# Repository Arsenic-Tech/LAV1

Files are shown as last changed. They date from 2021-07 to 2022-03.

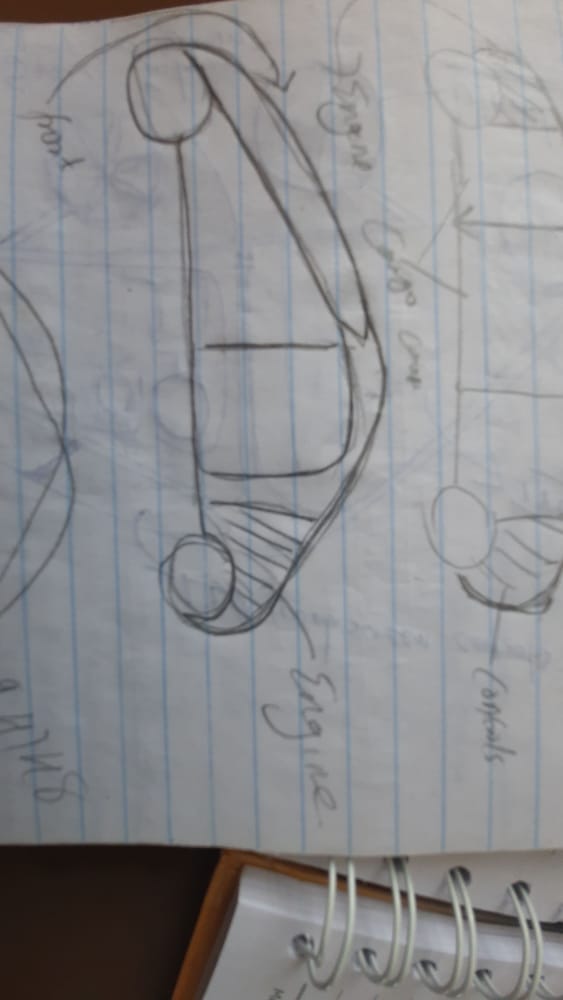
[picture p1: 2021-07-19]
IMGS/drone design2.jpg

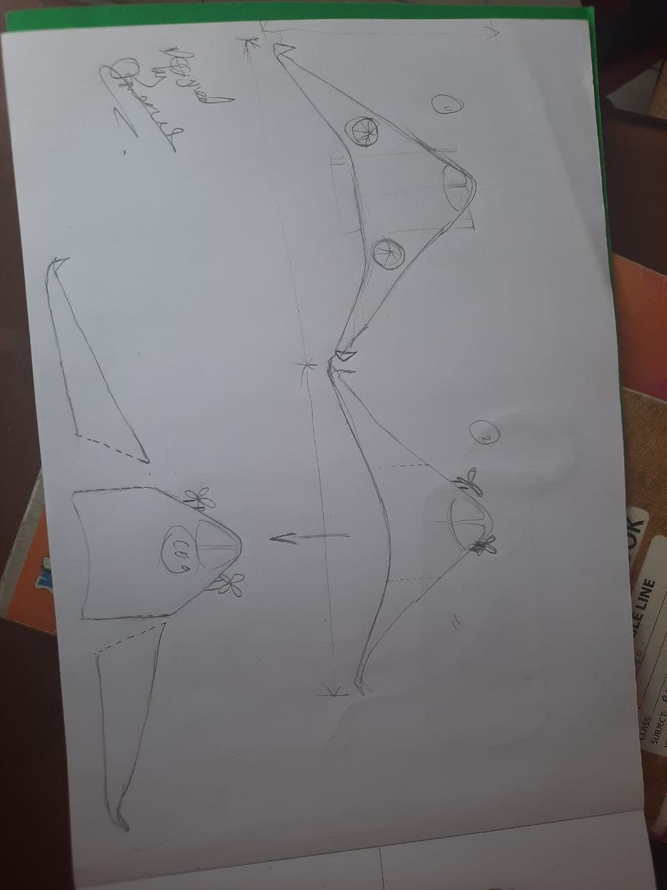
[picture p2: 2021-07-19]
IMGS/Drone design.jpg

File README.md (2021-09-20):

# LAV1
This is a project repo for the LAV1 containing all our designs and simulations for the model vehicle.

## Table of Contents
* General info
* Technologies
* Setup

### Genral Info
This repo is where our design files for the LAV1 vehicle are placed. The vehicle consists of a flying wing with props for vertical take off and landing. The vehicle was designed and analysed in OPENVSP and later transfered to [Freecad 0.19](https://www.freecadweb.org/downloads.php) and [Autocad Inventor 2020](https://www.autodesk.com/education/edu-software/overview) for parts design and further analysis. 

### Technologies
Project is created with
* OpenVsp
* Freecad
* Autocad Inventor

### Setup
To run this project, install it locally using Frecad or Inventor

```
$ git clone https://https://github.com/Ogweno-lab/LAV1
$ cd LAV1
# Open your preffered CAD software and open the design files
```

* **.vsp3** This are the OpenVsp files for various iterations of the LAV1
* **.ipt** These are the part files for the various parts of the N1 rocket model.
* **.stl** These are the 3D files of the respective parts.
* **.dwg** These are 2D drawing files of the repective part files.

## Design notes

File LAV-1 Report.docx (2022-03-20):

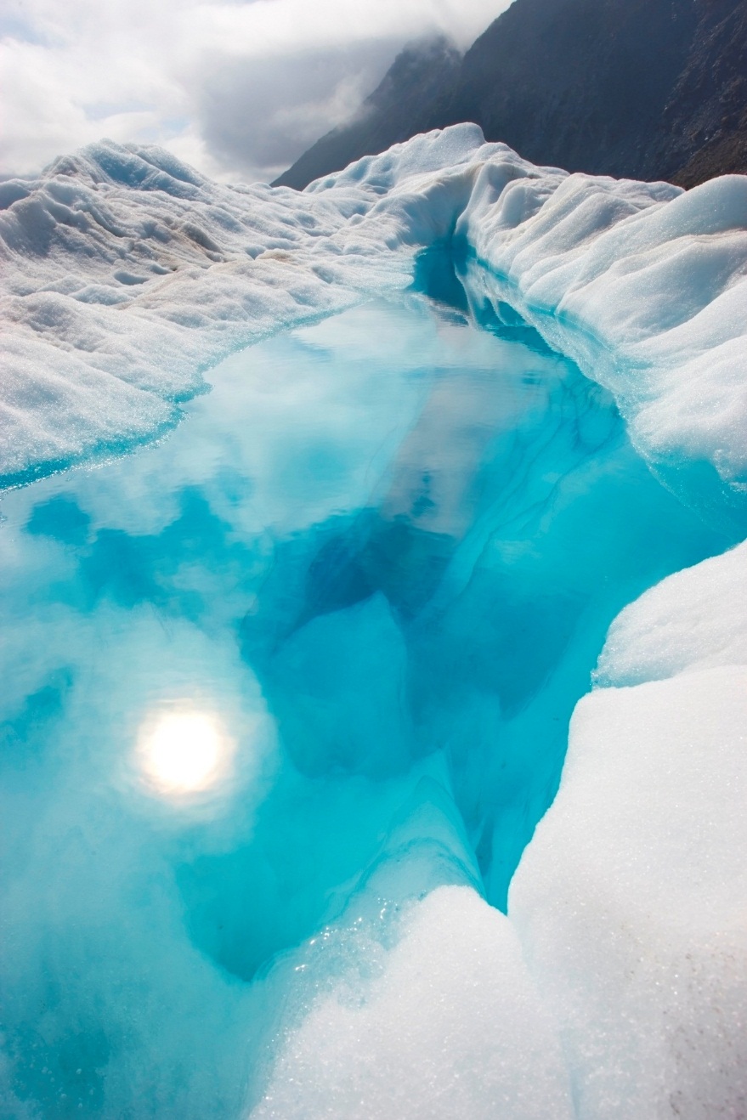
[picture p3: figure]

OGWENO E | LAV project | March 16, 2022

# AIRFRAME BUILD REPORT

8TH march 2022

# Objectives

The following were the objectives of the practical carried out:

1. To fabricate the wing sections and analyze their structural integrity.
2. To fabricate the airframe and perform load testing.
3. To test the performance of the BLDC motors.

# Materials

- Two forex boards [density=?]
- 2 A2-sized printings of the airfoil wing sections
- 1 BLDC motor, and ESC and a power converter.
- Umbrella aluminum wires.

# Methodology

[JKUAT, iPIC]

- The A2 papers were glued to the forex board and the airfoil wing sections cut out using a power saw cutting machine.
- Finishing was done on them using various grade sand papers.
- Using a hand-held drill, holes were made on the sections to allow for passage of the aluminum wires.

# Results and Insights

The power saw proved quite accurate in getting the general shapes of the airfoils which were then smoothed to their exact outlines using sandpapers. The following airfoil wing sections were produced.

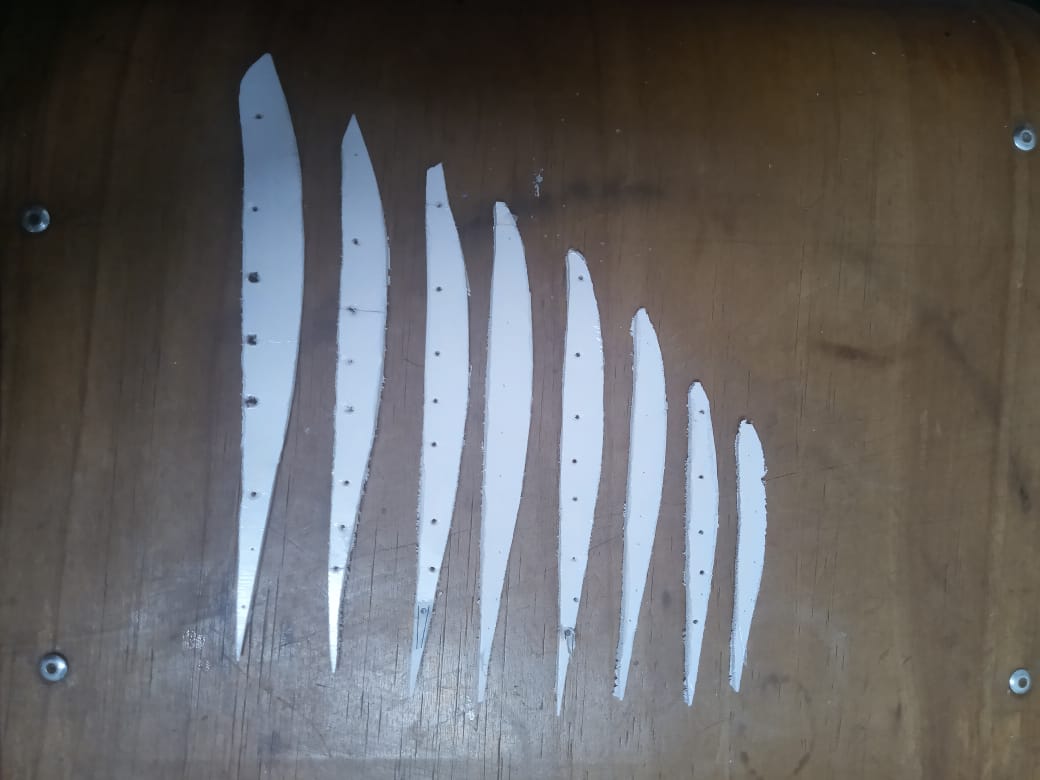
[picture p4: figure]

The airfoil sections however turned out to be of very small size and the material was also too weak and occasionally snapped. This snapping was further aggravated when we tried to enlarge the holes meant for passing of the aluminum connecting wires.

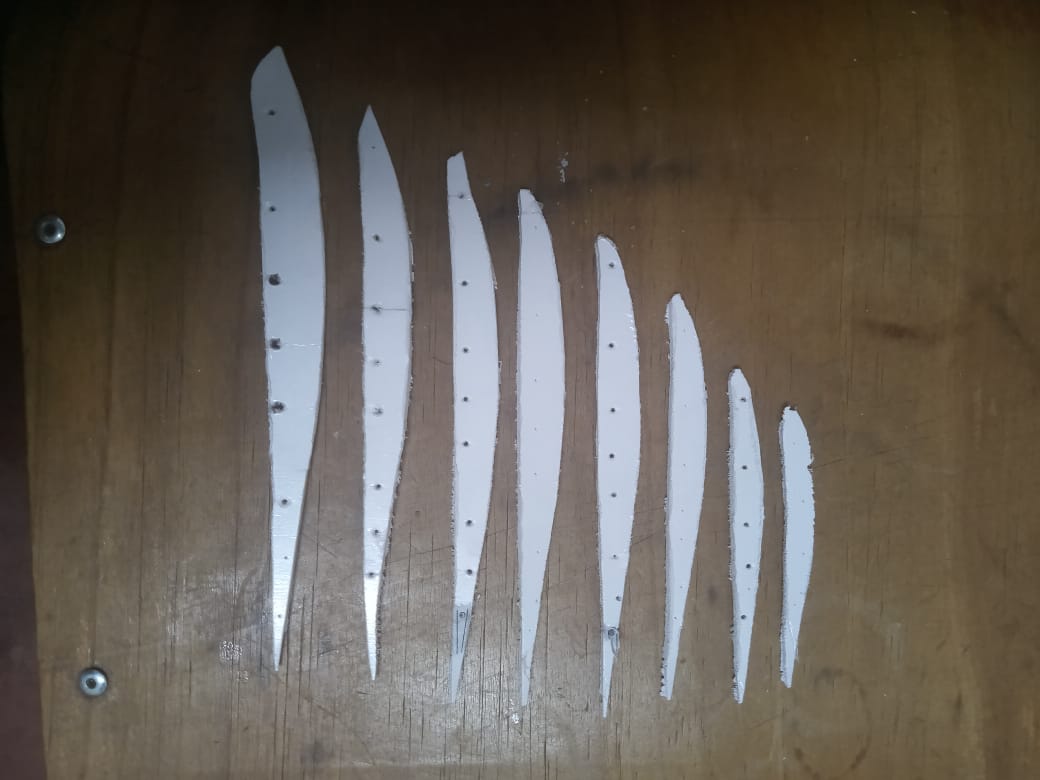
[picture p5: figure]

Due to the very weak nature and small size of the wing sections it was impossible to fabricate the entire airframe as any attempt to connect the sections using aluminum only led to further snapping. These were the main conclusions of the test:

1. Forex board was not a suitable material and alternative material was to be researched.
2. The size of the vehicle was relatively small and suggestions were made to increase the span to about 1 m to allow for larger sections and space for the electronic equipment.
3. The umbrella aluminum wires were also not desired and research into better material that improved structural integrity of the vehicle was advised.

Due to time constraints and unavailability of most of the power and electronics members, it was not possible to perform performance test on the motor. This was postponed to a later date.

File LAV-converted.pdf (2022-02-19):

# LAV-1 DESIGN PARAMETERS

## Introduction

The design of the design of the vehicle was done using OpenVSP (http://openvsp.org/) software. The software’s analysis tools were used to perform lift, drag, and stability analysis on the design. The design parameters were informed by studies on flying wing designs and general intuitive feeling of the designers.

The following terms are used:

AoA – Angle of attack.

cg – center of gravity

np – neutral point

SM – static margin

## 1. Span

A span of 0.5 was selected as it the vehicle was an RC model and the size was relatively easy to construct.

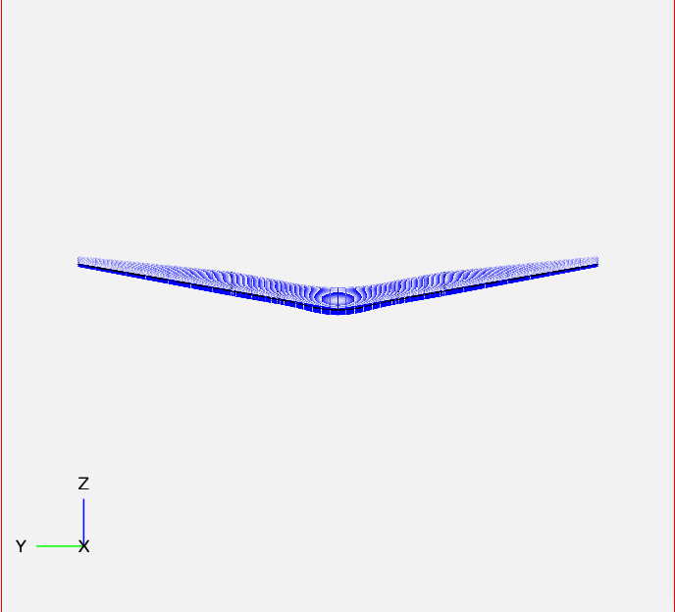
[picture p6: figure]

## 2. Cord

Based on the overall shape of the vehicle, a root cord of 0.23 and a tip cord of 0.08 were chosen. These gave the vehicle an aspect ratio of 2.88499 and taper ratio of 0.3478. It is generally preferred to keep the AR between 0.3 and 0.6 for model RC airplanes. A 0.4 TR has the least induced drag and highest lift coefficients at the tips. The impact on performance is however not much significant.

## 3. Sweep

The sweep of a wing provides a lot of leverage for the control surfaces and gives a large freedom space for the cog. The sweep also contributes to yaw stability of the vehicle.

A sweep of 40 deg was selected as it enabled a lot of area to be packed in a short span of .5

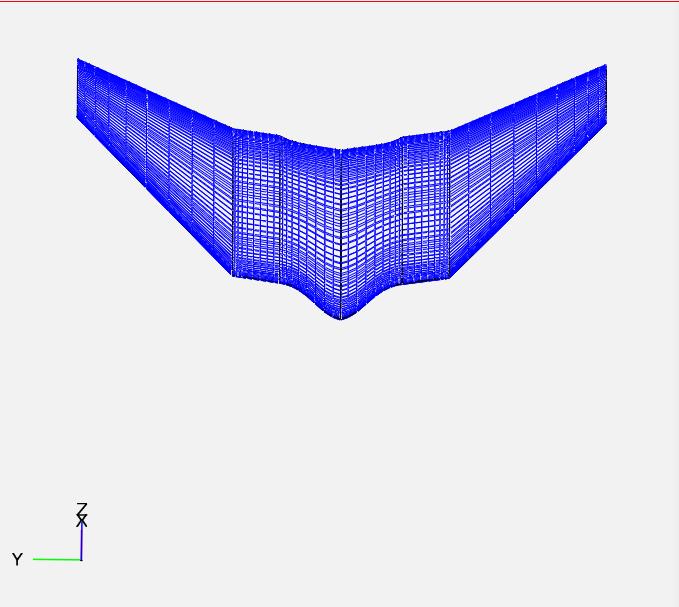
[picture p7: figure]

## 4. Dihedral

Dihedral contributes majorly to the roll stability of the airplane. A positive dihedral causes a positive stability of the aircraft. This effect was desired on the aircraft and therefore a dihedral angle of 10 deg was selected. This angle provided the optimum effect on lift and drag distributions after experimenting with different iterations.

## 5. Airfoil selection

Longitudinal stability is a major concern for flying wings as they lack a tail wing to counter act the nose up moment of the wings. To this stability, special airfoils have been developed for use in flying wings. A major sub-category of these airfoils are the reflexed airfoils. Due to their shape, they provide a self-countering moment in the plane. A section of a reflexed airfoil is shown below.

## Analysis and Insights:

These data were taken at the following conditions:

Using the OpenVSP analysis tools, stability analysis and performance analysis was done on the model.

The lift and drag curves showed a descent consistent increase with increase of AoA.

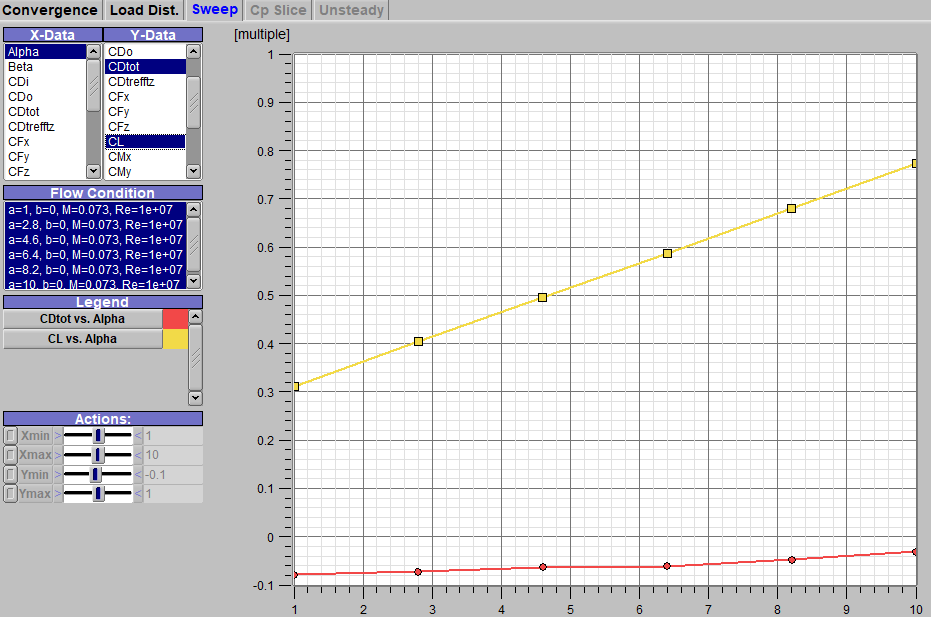
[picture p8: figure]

The span-wise load distribution was also plotted as shown below.

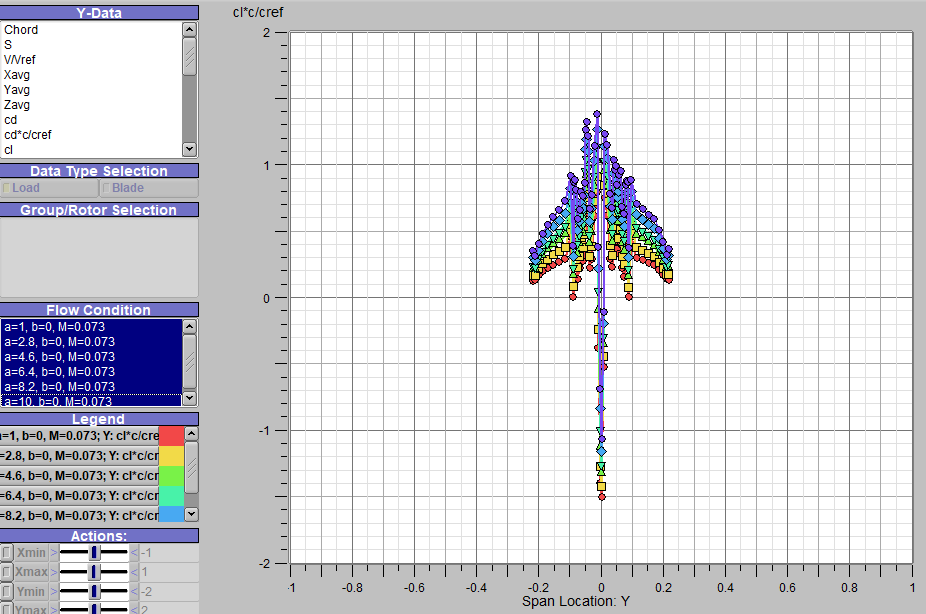
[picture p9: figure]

This was consistent with the expected results.

Analysis also resulted in a relatively stable plane with negligible moments along the different axes.

Longitudinal moments were generally positive. This indicates the plane would always have a tendency to nose down. However, this effect is negligible.

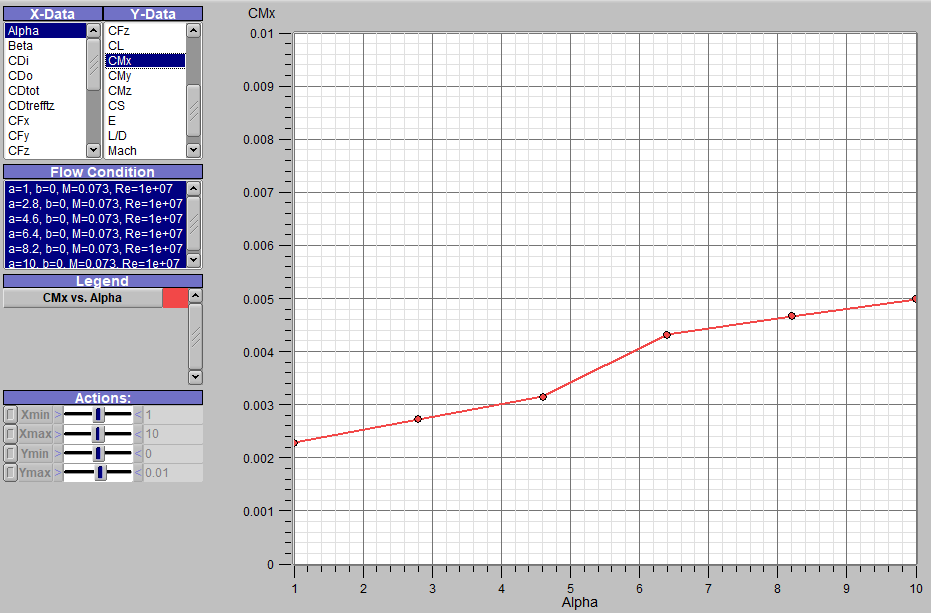
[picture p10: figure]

The y- and z- moments were generally negative, yet, also negligible. With increase in AoA, the Ymoments were relatively stable while the z-moments reduced.

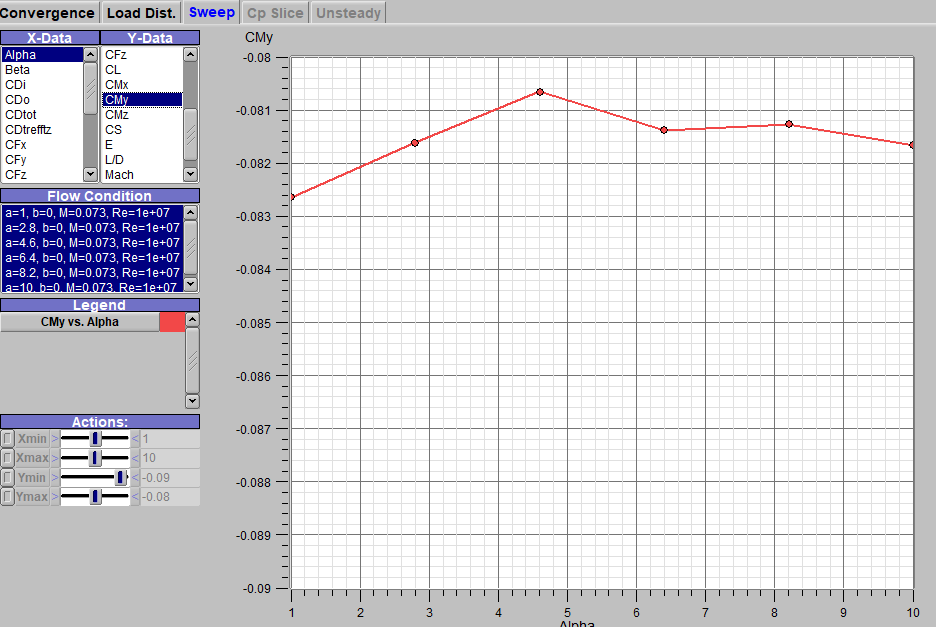
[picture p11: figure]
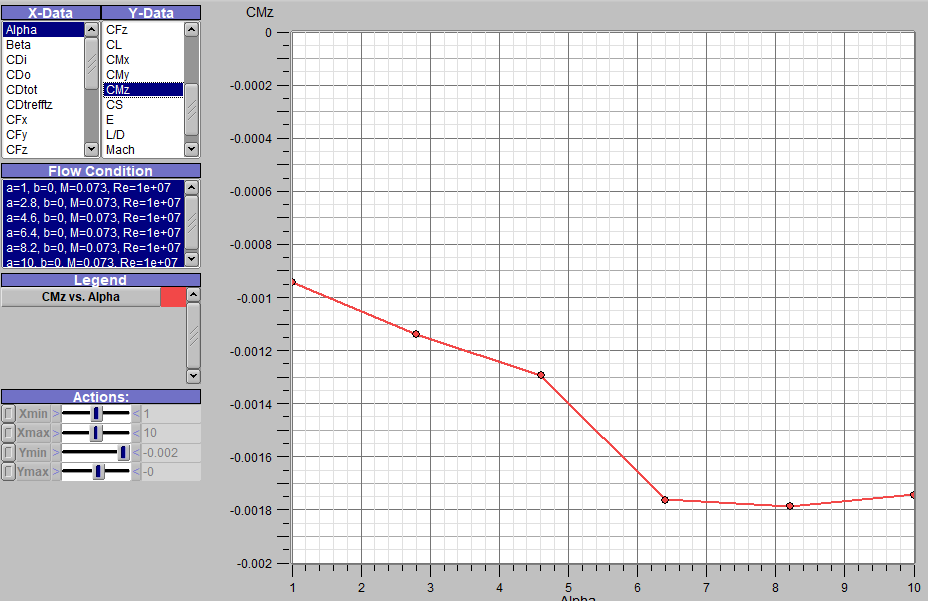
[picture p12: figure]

Other factors which affected the design process include the cg, np, and the SM.

np is the position of center of gravity at which stability is neutral. The x-axis position of the np was 0.1261728.

cg = np – SM*cord

The SM is the distance between cg and np, divided by the mean chord of the wing. A desirable SM is between 2% and 5%. These constrain the cg to between 0.0122478 and 0.1169228 which is a very small window.

The target cruise altitude of the vehicle is between 2 and 5 meters. A sample calculation is done to find the lift that would be produced during cruise flight. Using the lift equation;

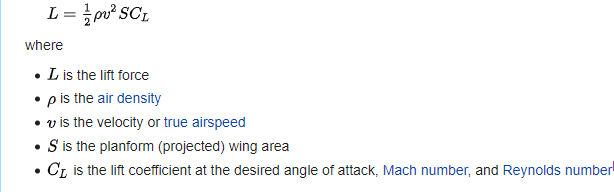
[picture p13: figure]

A lift force of 14N is achieved at velocity of 20m/s, with CL of 0.7 and S of 0.084042. This is barely 1.4kg.

## References

## - https://www.researchgate.net/publication/328916819_Eff ects_of_Taper_Ratio_on_Aircraft_Wing_Aerodynamic_Par

ameters_A_Comperative_Study (https://www.researchgate.net/publication/328916819_Effects_of_Taper_Ratio_on_Aircraft_Wing_Aerodynamic_Parameters_A_Comperative_Study)

## - Basic Design of Flying Wing Models (https://www.mh-aerotools.de/airfoils/flywing1.htm) - Flying Wing – Design Notes (https://rcbeacon.com/blog/?page_id=2095) - https://www.youtube.com/watch?v=x2Cn3vIb6gw

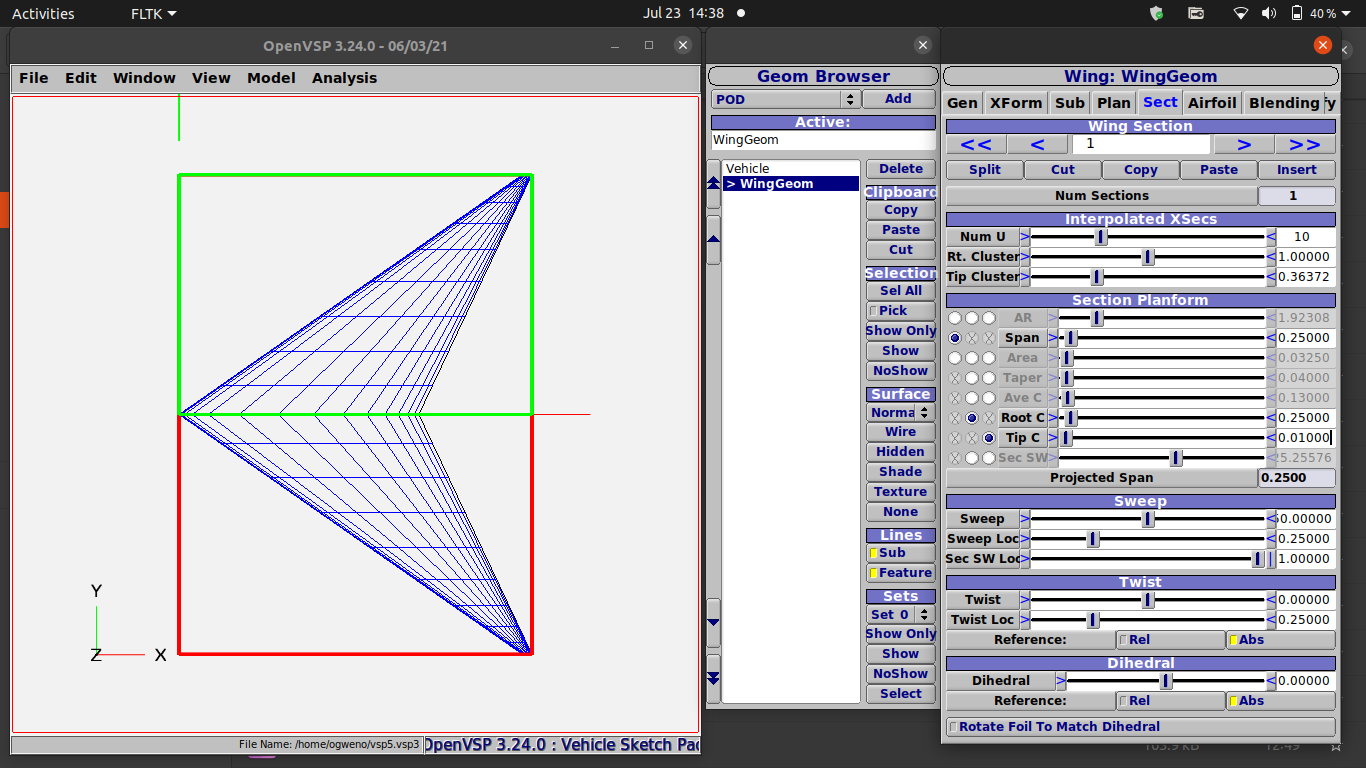
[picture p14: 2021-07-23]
IMGS/Vsp5 design.png

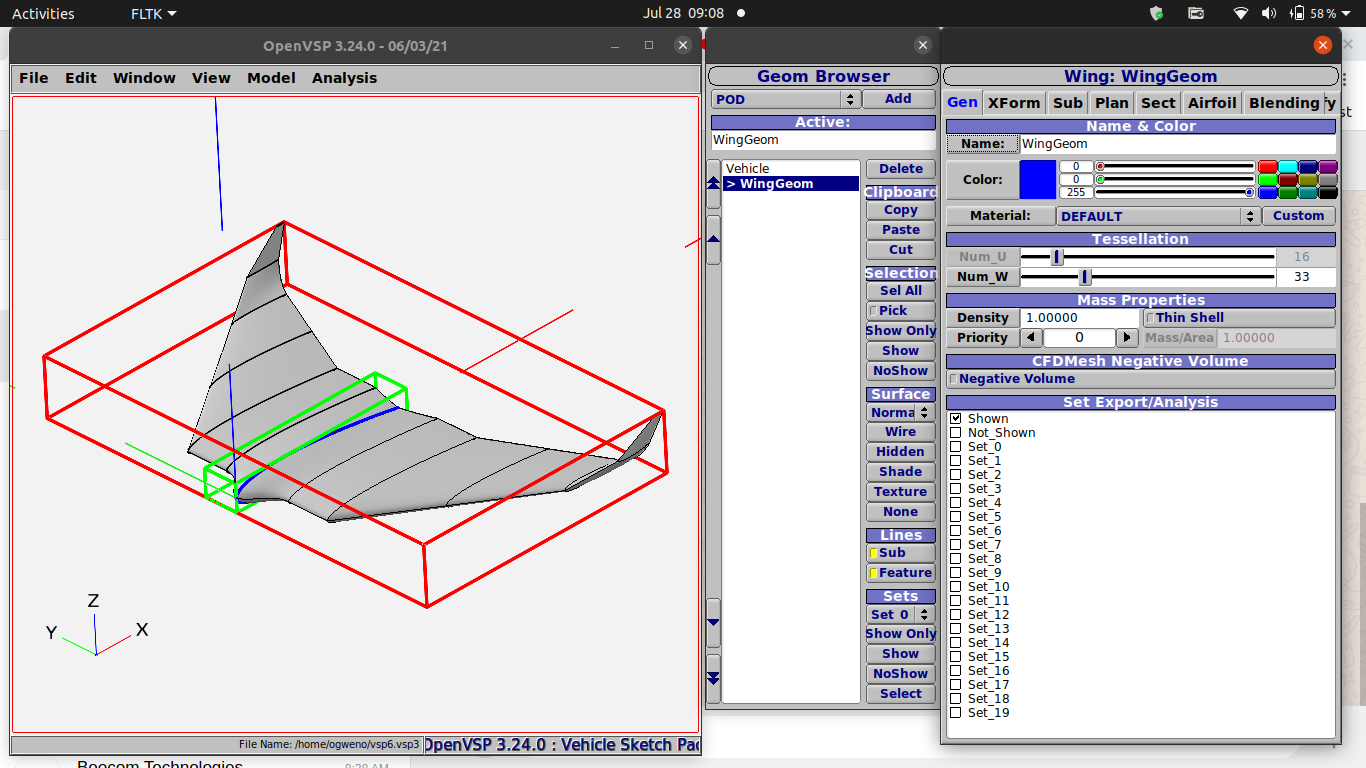
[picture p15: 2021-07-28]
IMGS/VSP6 design.png

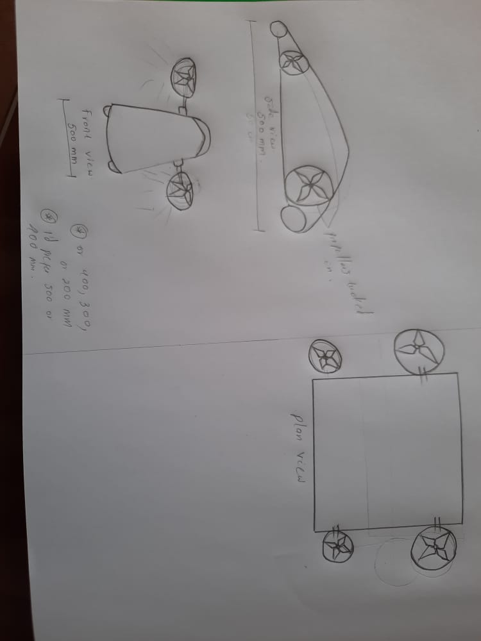
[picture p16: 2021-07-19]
IMGS/drone design1.jpg

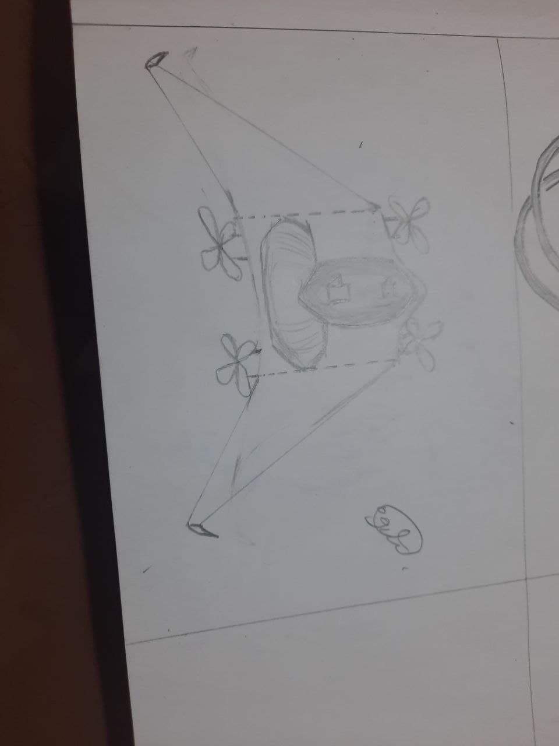
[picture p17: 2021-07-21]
IMGS/Drone design3.jpg

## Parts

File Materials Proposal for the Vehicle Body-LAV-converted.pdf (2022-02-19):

Materials Proposal for the Vehicle Body.

The following materials have been proposed by the design team for the vehicle body and frame.

### 1. Ribs:

For the ribs, 3 mm Forex board was proposed. The board offers excellent strength while also offering an easy shaping process as they can easily be cut by a pair of scissors.

To produce the 11 ribs, 2 ailerons, and 2 wing tips, two pieces of 60 cm by 60 cm Forex foam boards would suffice. The total cost would be KES. 500.

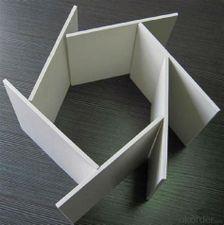
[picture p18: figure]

2. Cross Links:

The cross links are a major part of the frame as they bare a majority of the loads. They connect the ribs and all other structures together.

As an efficient way of cutting on costs, Umbrella wires were suggested as they are made of light aluminum. They also have turning joints in them which will ease the work of getting the different angles in the vehicle body. 11 of these wires have already been collected and are available at no cost.

3. Longitudinal links:

To improve the refinement of the final shape, it is necessary to have other links running longitudinally over the vehicle. They would offer added structural support but their main job would be to define the airfoil shape across the vehicle.

Broomsticks, a light and cheap option were suggested. One broomstick would be enough at a cost of KES. 50

4. Wing Cover:

To conceal the insides of the vehicle and to offer a smooth finish, it is necessary to have a surface cover. Several materials have been suggested including:

- A plain carpet
- Tape
- Nylon.

The team is yet to decide on the exact material.

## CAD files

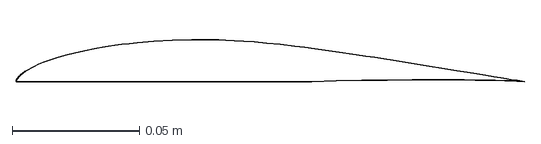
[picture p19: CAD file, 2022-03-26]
CAD Files/Rib1.dxf
0.2 x 0.0169 m

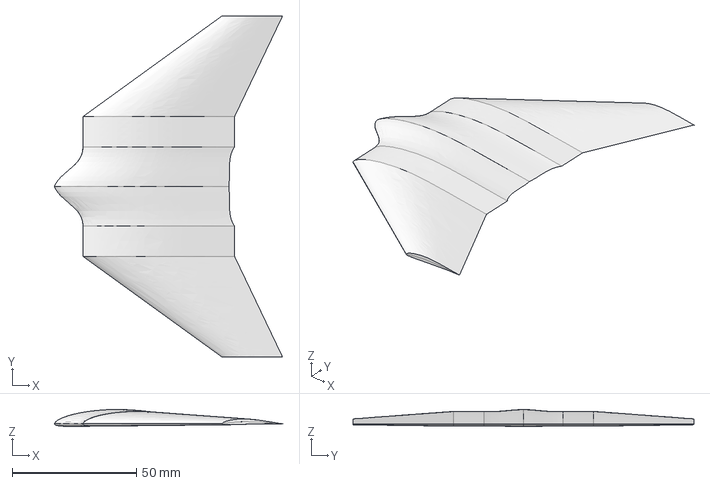
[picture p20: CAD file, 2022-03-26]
CAD Files/VSP76.FCStd
91.7 x 137.0 x 6.83 mm

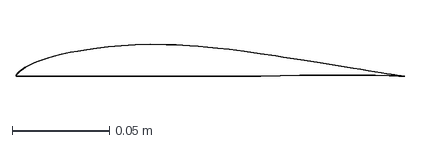
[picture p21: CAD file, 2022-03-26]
CAD Files/Rib2.dxf
0.2 x 0.0169 m

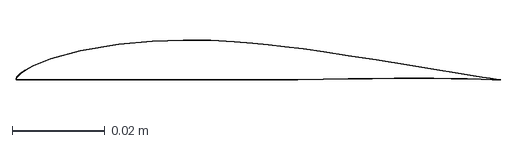
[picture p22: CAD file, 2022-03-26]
CAD Files/Rib6.dxf
0.104 x 0.00858 m

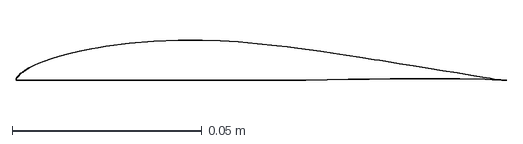
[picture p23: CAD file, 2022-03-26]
CAD Files/Rib5.dxf
0.129 x 0.0107 m

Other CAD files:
CAD Files/Rib3.dwg
CAD Files/Rib4.dwg
CAD Files/VSP76-0.SLDPRT
CAD Files/Middle Rib + 1, 2, 3, 4, 5, 6.dwg
CAD Files/VSP76-autocad.dwg
CAD Files/Flatstringers.ipt
CAD Files/Midrib-stringers.ipt
CAD Files/Platestringers.ipt
CAD Files/Stringerguides.ipt
CAD Files/VSP76-0.ipt
CAD Files/Vsp-m.ipt
CAD Files/Vsp76Vsp76.ipt
CAD Files/Vsp76sVsp76.ipt
vsp74.ipt

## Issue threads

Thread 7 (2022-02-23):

Determine all electronic components found in the vehicle

WashingtonKK, 2022-02-23:
This is to enable the power team to come up with comprehensive power requirements for the entire vehicle.

Ogweno-lab, 2022-02-23:
Who is this assigned to?

WashingtonKK, 2022-02-23:
Byron, however he is not part of this github organization

chepngenoh-kericho, 2022-03-18:
[lav - 1 electronic components and power.odt](https://github.com/Arsenic-Tech/LAV1/files/8302360/lav.-.1.electronic.components.and.power.odt)

chepngenoh-kericho, 2022-03-18:
The  file above is a just a frame work of what we will need and we will be updating the list

Closed 2022-03-18.

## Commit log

2021-07-21 Add files via upload
    Another design by me. Like the other two, the wings are also extractable. I like this one most. What do you guys think?
2021-07-23 Add files via upload
    Worked on the wing planform today
    After trying out several ideas, this is the best I came up with today.
    I've uploaded the .vsp3 of the design-anyone can download it and do analysis on the same and suggest any improvements.
2021-07-23 Add files via upload
    The .vsp3 file for the planform design of the flying wing
2021-07-23 Add files via upload
    I think this one looks better, only needs a slight adjustment on the trailing edge, add the props and we're good to go!
2022-01-13 Add files via upload
    Ribs design
    [vsp74.ipt]
2022-02-19 Add files via upload
    Materials proposal for the body
